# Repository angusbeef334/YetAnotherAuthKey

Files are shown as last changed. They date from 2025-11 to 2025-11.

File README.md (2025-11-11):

# YetAnotherAuthKey
A Raspberry Pi RP2354 based PCB that can be flashed with the [pico-fido](https://github.com/polhenarejos/pico-fido) firmware to act as a security key similar to Yubikey, because Yubikeys are expensive and I'm broke.

Made for Hack Club [Blueprint](https://blueprint.hackclub.com)

KiCad 9 format, all of the symbol/footprint libraries should be included in the repo. 

RP2350 and related components symbols/footprints were obtained from [Raspberry Pi](https://datasheets.raspberrypi.com/rp2350/Minimal-KiCAD.zip).







LCSC bom (most of these have MOQs)
| Id | Designator | Footprint | Quantity | Designation | LCSC Part Number | Ext Price USD |
|----|---|---|---|---|---|---|
| 1  | C8,C12,C10,C11,C17,C15,C19,C18,C14,C16,C13 | C_0402_1005Metric | 11 | 100n | C1525 | 0.12 |
| 2  | C1,C2 | C_0603_1608Metric | 2 | 10u | C19702 | 0.29 |
| 3  | SW1 | SW_Push_SPST_NO_Alps_SKRK | 1 | SW_Push | C115357 | 0.64 |
| 4  | C6,C9,C7,C5 | C_0402_1005Metric | 4 | 4.7u | C368809 | 0.31 |
| 5  | U2 | SOT-23 | 1 | MCP1700x-330xxTT | C39051 | 1.98 |
| 6  | R3,R2 | R_0402_1005Metric | 2 | 27 | C138021 | 0.07 |
| 7  | Y1 | Crystal_SMD_3225-4Pin_3.2x2.5mm | 1 | ABM8-272-T3 | C20625731 | 1.77 |
| 8  | J1 | USB_A_Molex_48037-2200_Horizontal | 1 | USB_A | C2681564 | 0.65 |
| 9  | L1 | C_0402_1005Metric | 1 | 3.3u | C51412 | 0.9 |
| 10 | R4,R5 | R_0402_1005Metric | 2 | 1k | C106235 | 0.06 |
| 11 | R6 | R_0402_1005Metric | 1 | 33 | C138002 | 0.07 |
| 12 | U1 | RP2350-QFN-60-1EP_7x7_P0.4mm_EP3.4x3.4mm_ThermalVias | 1 | RP2350_60QFN | C41378174 | 2.49 |
| 13 | C3,C4 | C_0402_1005Metric | 2 | 15p | C86285 | 0.29 |

Total: 9.64 USD

PCB:
14.45 mm* 34.35 mm, green soldermask, leadfree HASL - 3.3 USD + 3 USD stencil

Total: 16 USD + shipping

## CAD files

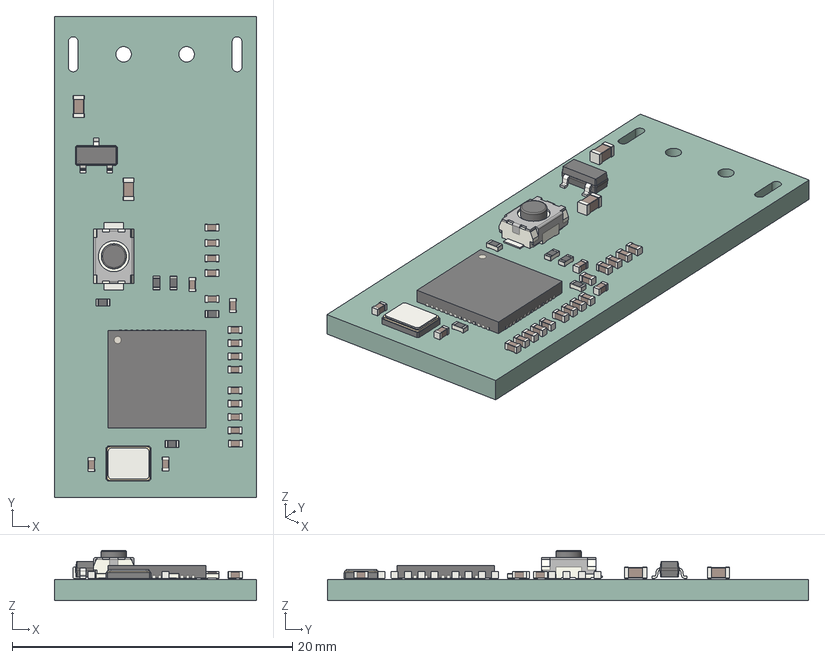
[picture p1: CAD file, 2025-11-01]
cad/YetAnotherAuthKey.step
14.4 x 34.3 x 3.59 mm
C_0402_1005Metric x 18
C_0603_1608Metric x 2
SW_Push_SPST_NO_Alps_SKRK
SOT-23
R_0402_1005Metric x 5
Crystal_SMD_3225-4Pin_3.2x2.5mm
QFN-56-1EP_7x7mm_P0.4mm_EP5.6x5.6mm
YetAnotherAuthKey_PCB

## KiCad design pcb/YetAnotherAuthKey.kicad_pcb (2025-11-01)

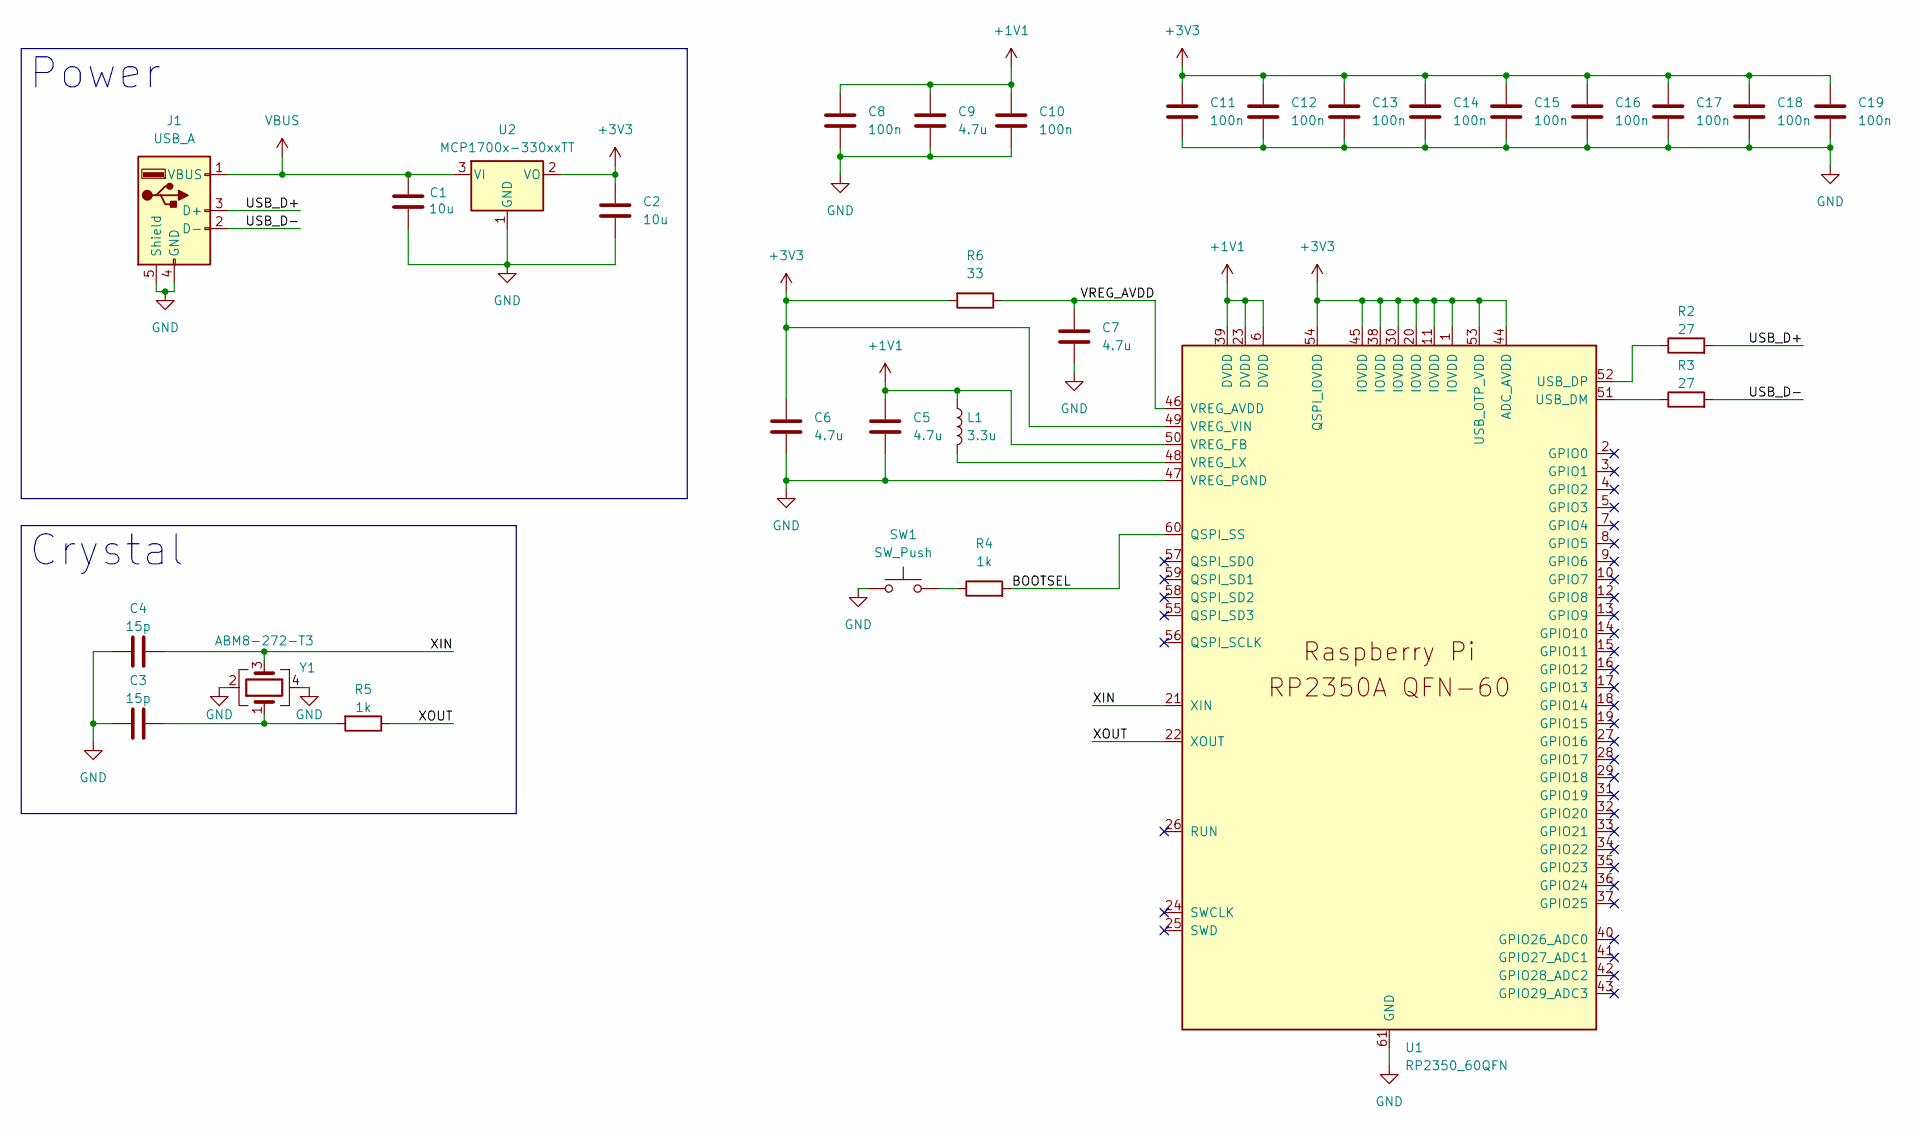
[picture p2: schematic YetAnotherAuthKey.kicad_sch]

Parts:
C1, C2: 10u; C_0603_1608Metric
C3, C4: 15p; C_0402_1005Metric
C5, C6, C7, C9: 4.7u; C_0402_1005Metric
C8, C10, C11, C12, C13, C14, C15, C16, C17, C18, C19: 100n; C_0402_1005Metric
J1: USB_A; USB_A_Molex_48037-2200_Horizontal
L1: 3.3u; C_0402_1005Metric
R2, R3: 27; R_0402_1005Metric
R4, R5: 1k; R_0402_1005Metric
R6: 33; R_0402_1005Metric
SW1: SW_Push; SW_Push_SPST_NO_Alps_SKRK
U1: RP2350_60QFN; RP2350-QFN-60-1EP_7x7_P0.4mm_EP3.4x3.4mm_ThermalVias
U2: MCP1700x-330xxTT; SOT-23
Y1: ABM8-272-T3; Crystal_SMD_3225-4Pin_3.2x2.5mm

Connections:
+1V1: C5.1, C8.1, C9.1, C10.1, L1.1, U1.6 (DVDD), U1.23 (DVDD), U1.39 (DVDD), U1.50 (VREG_FB)
+3V3: C2.1, C6.1, C11.1, C12.1, C13.1, C14.1, C15.1, C16.1, C17.1, C18.1, C19.1, R6.2, U1.1 (IOVDD), U1.11 (IOVDD), U1.20 (IOVDD), U1.30 (IOVDD), U1.38 (IOVDD), U1.44 (ADC_AVDD), U1.45 (IOVDD), U1.49 (VREG_VIN), U1.53 (USB_OTP_VDD), U1.54 (QSPI_IOVDD), U2.2 (VO)
/BOOTSEL: R4.2, U1.60 (QSPI_SS)
/USB_D+: J1.3 (D+), R2.2
/USB_D-: J1.2 (D-), R3.2
/VREG_AVDD: C7.1, R6.1, U1.46 (VREG_AVDD)
/XIN: C4.1, U1.21 (XIN), Y1.3
/XOUT: R5.1, U1.22 (XOUT)
GND: C1.1, C2.2, C3.2, C4.2, C5.2, C6.2, C7.2, C8.2, C9.2, C10.2, C11.2, C12.2, C13.2, C14.2, C15.2, C16.2, C17.2, C18.2, C19.2, J1.4 (GND), J1.5 (Shield), SW1.1, U1.47 (VREG_PGND), U1.61 (GND), U2.1 (GND), Y1.2, Y1.4
unnamed: C3.1, R5.2, Y1.1
unnamed: R4.1, SW1.2
unnamed: R3.1, U1.51 (USB_DM)
unnamed: R2.1, U1.52 (USB_DP)
unnamed: L1.2, U1.48 (VREG_LX)
VBUS: C1.2, J1.1 (VBUS), U2.3 (VI)

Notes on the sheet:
Crystal
Power

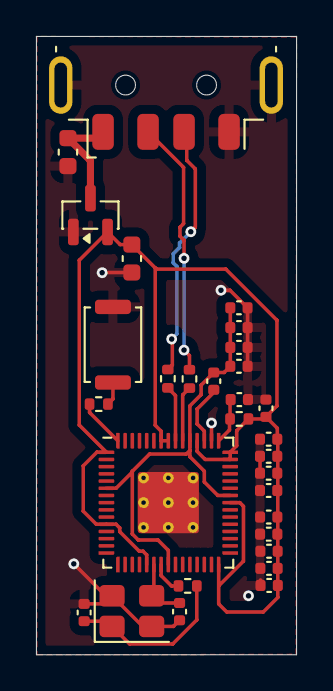
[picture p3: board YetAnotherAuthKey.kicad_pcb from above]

Board: 2 copper layers, 14.4 x 34.3 mm, 30 parts (0 on the bottom side), 15 nets.

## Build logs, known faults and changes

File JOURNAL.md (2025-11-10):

<!--
  ===================    !!READ THIS NOTICE!!   ====================
  DO NOT edit this file manually. Your changes WILL BE OVERWRITTEN!
  This journal is auto generated and updated by Hack Club Blueprint.
  To edit this file, please edit your journal entries on Blueprint.
  ==================================================================
-->

## 10/6/2025 - Did the schematic  

Decent progress, created the schematic based on the QFN60 version of RP2350. There is no external flash as I will most likely be using RP2354, which has 2MB onboard flash and _should_ be enough space. I will probably clean up the schematic first, then route the PCB.



## 11/1/2025 - Routed the PCB  

Switched to a USB-A plug because it's easier to work with and the computer I will use it on has a type A port.

Routed the PCB, rerouted the PCB, and then rerouted it again.





## 11/10/2025 - Finish  

I made the fabrication outputs and finished the GitHub repo.

The final costs are attached below, I will be soldering the board myself.

All prices in USD, totals to less than $30.




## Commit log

2025-10-06 place components
    [YetAnotherAuthKey.kicad_pcb]
2025-10-07 clean schematic
    [YetAnotherAuthKey.kicad_sch]
2025-10-07 add missing grounds
    [YetAnotherAuthKey.kicad_sch]
2025-11-01 finish pcb
    [YetAnotherAuthKey-B_Cu.gbr, YetAnotherAuthKey-B_Mask.gbr, YetAnotherAuthKey-B_Paste.gbr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]
2025-11-01 add bom
    [bom.csv]
2025-11-01 add lcsc parts info
    [bom.csv]
2025-11-01 fix structure, add cad model
    [YetAnotherAuthKey-B_Cu.gbr, YetAnotherAuthKey-B_Mask.gbr, YetAnotherAuthKey-B_Paste.gbr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]
